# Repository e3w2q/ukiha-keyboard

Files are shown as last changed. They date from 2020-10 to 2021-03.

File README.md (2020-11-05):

# Ukiha




Small key pitch 5x12 ortholinear keyboard.

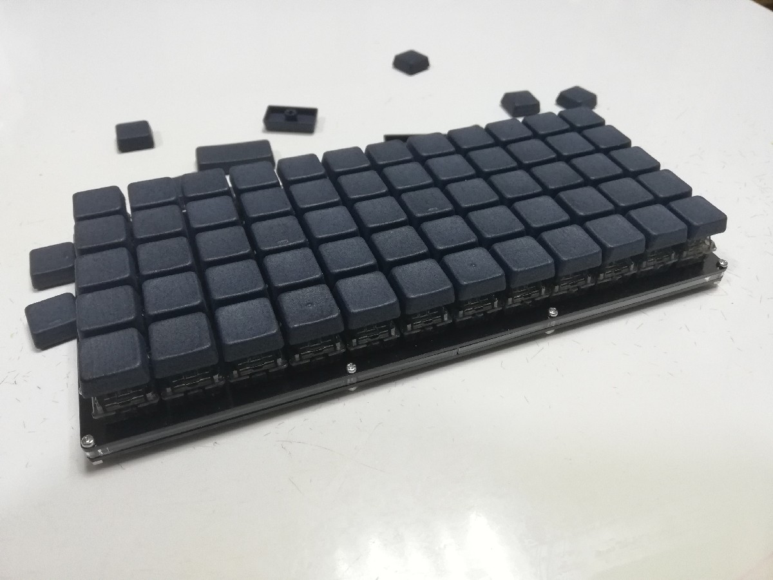
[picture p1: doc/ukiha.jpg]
ukiha


## What is the Ukiha?

The Ukiha is a 5x12 ortholinear keyboard like the Preonic and JJ50, but with a smaller key pitch of 16mm instead of 19.05mm.

I like expantable keyboard boards like [SU120](https://github.com/e3w2q/su120-keyboard) and [te96](https://github.com/e3w2q/te96-keyboard), but in this case I designed a keyboard that I genuinely wanted.

The *Ukiha* (浮葉) means "floating leaf" and is taken from the Japanese classic, *Pillow Book* (枕草子).

In the book, there is an example of a very small floating lotus leaf taken from a pond as a lovely thing.

うつくしきもの。(中略) 蓮の浮葉のいとちひさきを、池より取りあげたる。(枕草子 第百五十一段より)

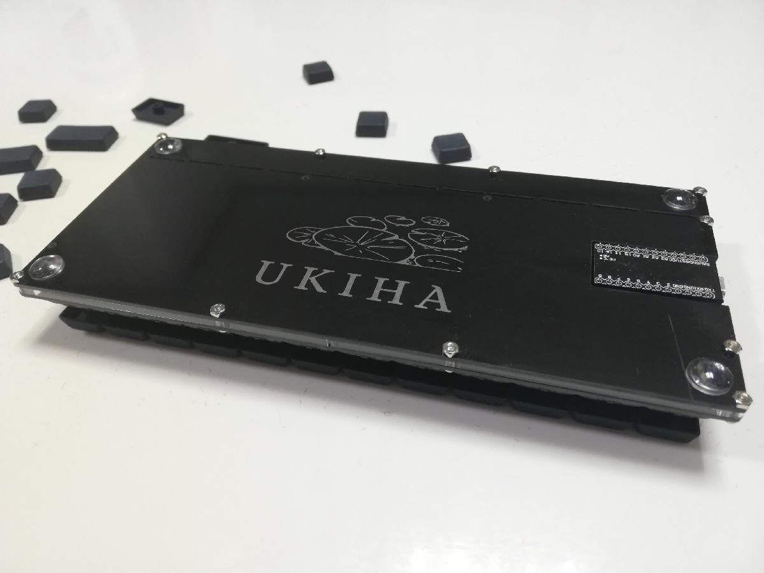
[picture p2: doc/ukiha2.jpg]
ukiha2


## Why open source?

Anyone interested in small key pitch keyboard could try.

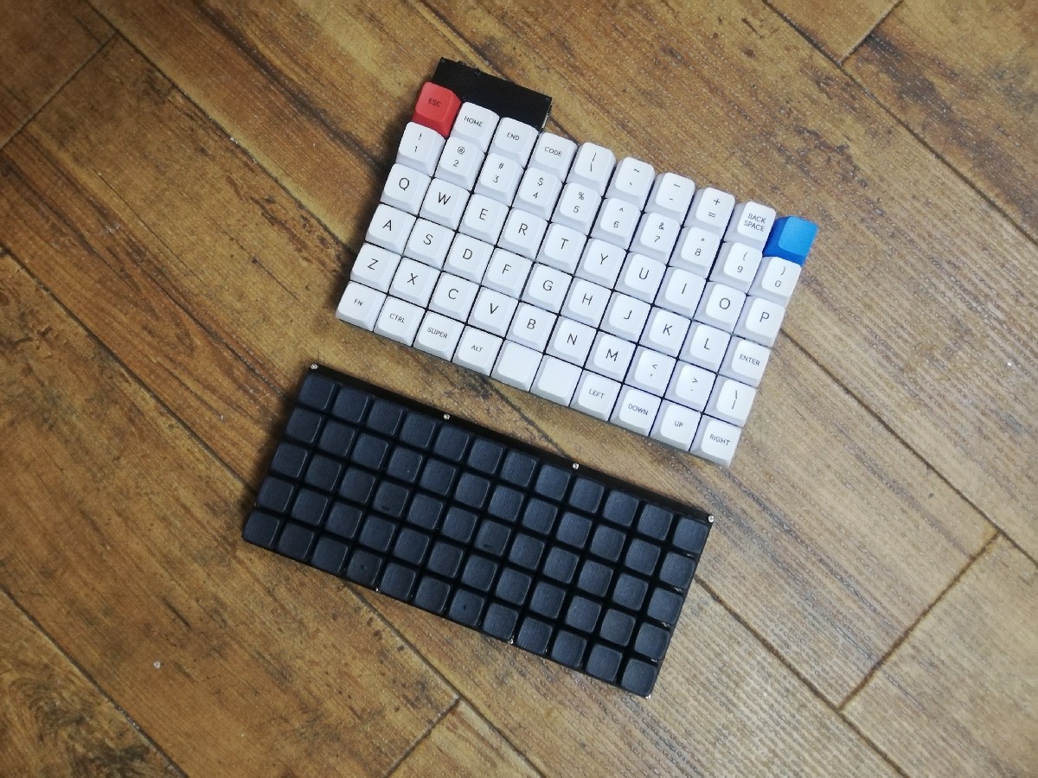
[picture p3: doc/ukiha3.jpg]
ukiha3


## Customizability

The 4 keys in the middle of the bottom row can be replaced with 2U.

You can take off the top row and make it into a 4x12 keyboard like Planck and JJ40.

## Link

[Hardware data (PCB)](pcb/)

[Firmware](https://github.com/e3w2q/qmk_firmware/tree/e3w2q/keyboards/e3w2q/ukiha)

[PCBの入手方法](doc/pcb_order_guide_jp.md)

[パーツリスト](doc/bom_list_jp.md)

[ビルドガイド](doc/readme_jp.md)

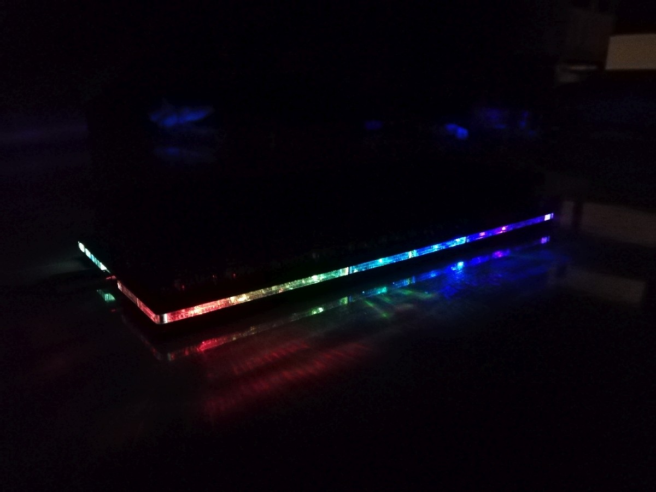
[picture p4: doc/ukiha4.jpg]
ukiha4


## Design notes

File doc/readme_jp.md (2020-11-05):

# 浮葉 ビルドガイド

<!-- TOC -->

- [浮葉 ビルドガイド](#浮葉-ビルドガイド)
    - [必要なパーツ](#必要なパーツ)
    - [使用する道具、消耗品](#使用する道具消耗品)
    - [ビルドガイド](#ビルドガイド)
        - [Pro Microのもげ防止加工](#pro-microのもげ防止加工)
        - [基板側面のヤスリがけ（お好みで）](#基板側面のヤスリがけお好みで)
        - [基板側面の塗装（お好みで）](#基板側面の塗装お好みで)
        - [はんだ付けのイメージトレーニング](#はんだ付けのイメージトレーニング)
        - [ダイオードの取り付け](#ダイオードの取り付け)
        - [キースイッチの取り付け](#キースイッチの取り付け)
        - [Pro Microの取り付け](#pro-microの取り付け)
        - [テープLEDの取り付け](#テープledの取り付け)
        - [ミドルプレート、ボトムプレートの取り付け](#ミドルプレートボトムプレートの取り付け)
        - [キーキャップの取り付け](#キーキャップの取り付け)
        - [ゴム足の取り付け](#ゴム足の取り付け)
        - [ファームウェアの書き込み](#ファームウェアの書き込み)
    - [トラブルシューティング](#トラブルシューティング)

<!-- /TOC -->

## 必要なパーツ

[浮葉 パーツリスト](bom_list_jp.md)をご覧ください。

## 使用する道具、消耗品

[使用する道具、消耗品](tool_guide_jp.md)におすすめの道具類、注意事項等をまとめましたのでご覧ください。

## ビルドガイド

### Pro Microのもげ防止加工

Pro Microにエポキシ接着剤を盛って、簡単にはもげないようにします。

参考1:[ProMicroのモゲ防止ついでにQMK_Firmwareを書き込む - Qiita](https://qiita.com/hdbx/items/2f3e4ddfcadda2a5578e)
参考2:[もげ予防 - Self-Made Keyboards in Japan](https://scrapbox.io/self-made-kbds-ja/%E3%82%82%E3%81%92%E4%BA%88%E9%98%B2)

エポキシ接着剤の2液を混ぜます。

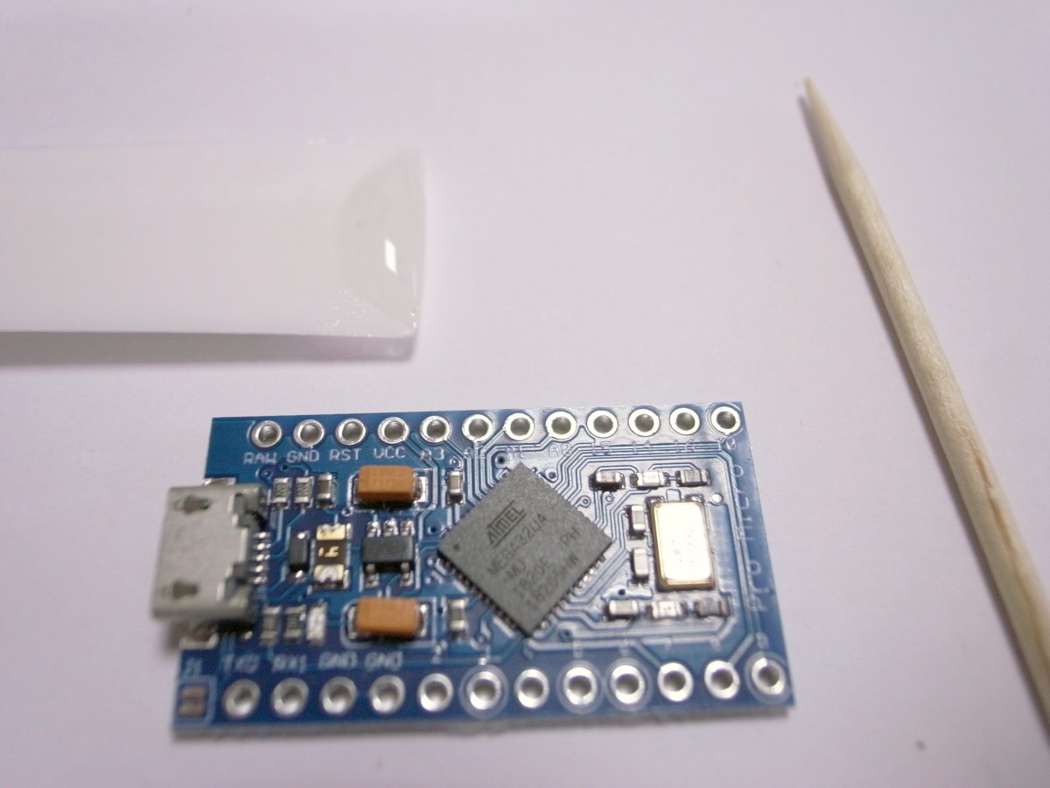
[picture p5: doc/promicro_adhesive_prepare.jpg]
adhesive_prepare


接着剤を付け始める前にMicro USBコネクタを横から見てください。側面に穴が開いています。この穴に接着剤が入ると端子が入らなくなったり、入りにくくなったりします。

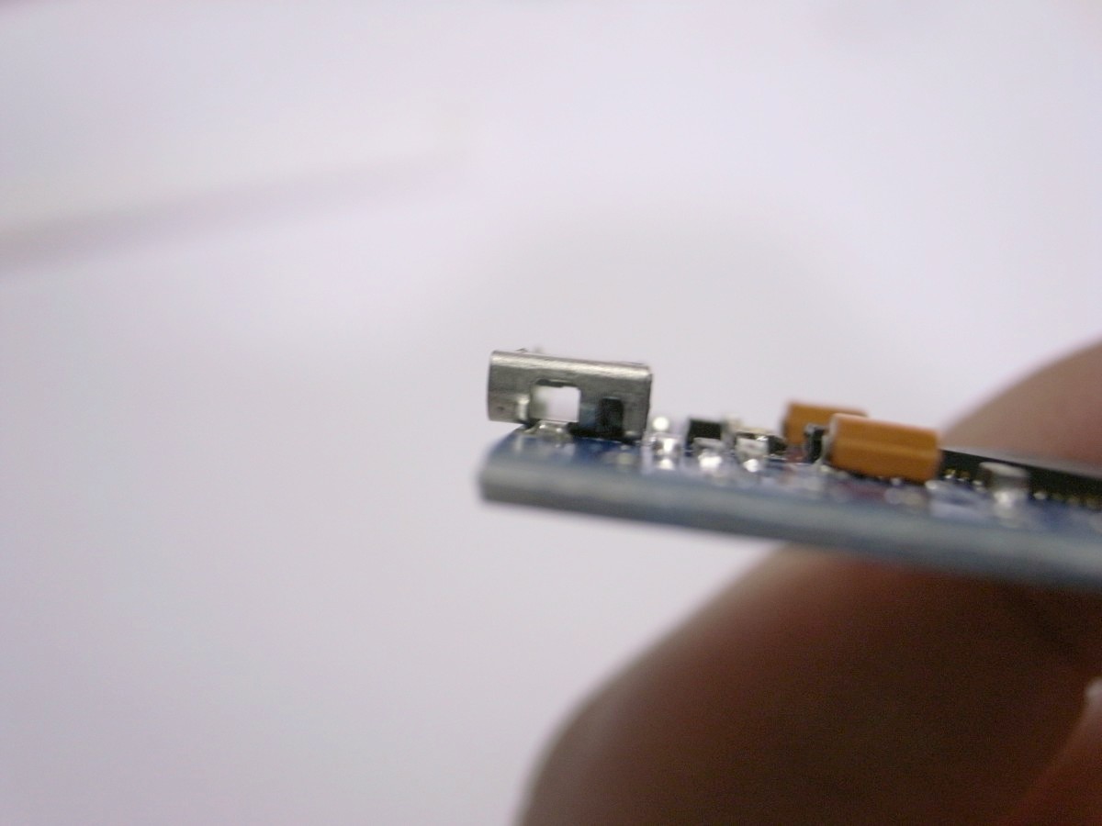
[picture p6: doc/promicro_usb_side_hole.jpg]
usb_side_hole


この穴を避けて、つまようじなどで接着剤を盛っていきます。

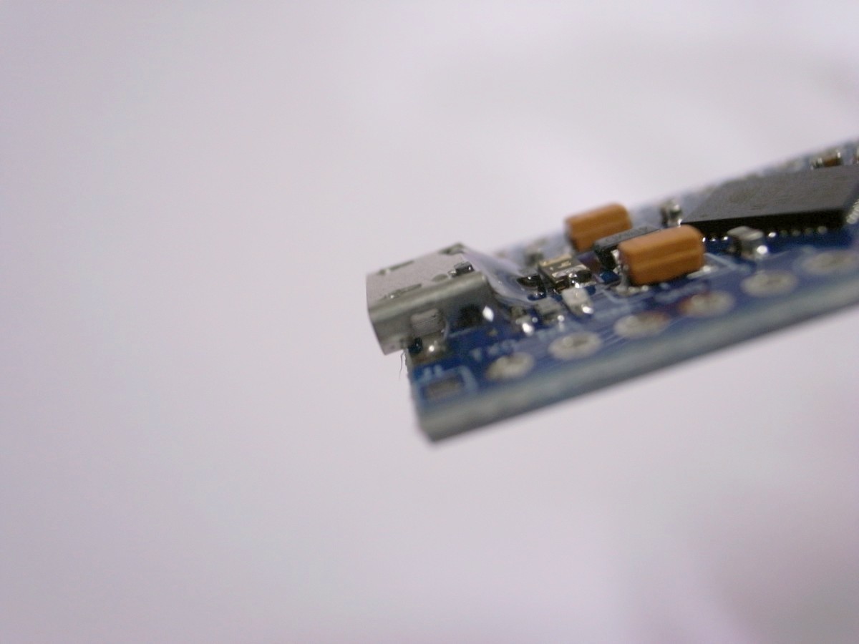
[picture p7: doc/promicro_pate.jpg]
promicro_pate


乾くまで置いておきます。

### 基板側面のヤスリがけ（お好みで）

基板の側面にザラつきがある場合、机に紙ヤスリを置き、その上で基板のバリがある側面をヤスリがけします。Pro Microの側面もヤスリがけします。

### 基板側面の塗装（お好みで）

基板の側面を太めのマジックで塗ります。細いマジックだとムラが出やすいので太めのマジックで一度に塗るとよいです。Twitterで@swan_matchさんにガンダムマーカーがよいと教えてもらいましたが、確かにきれいに塗れました。塗る場合はPro Microの側面も塗っておくとよいです。

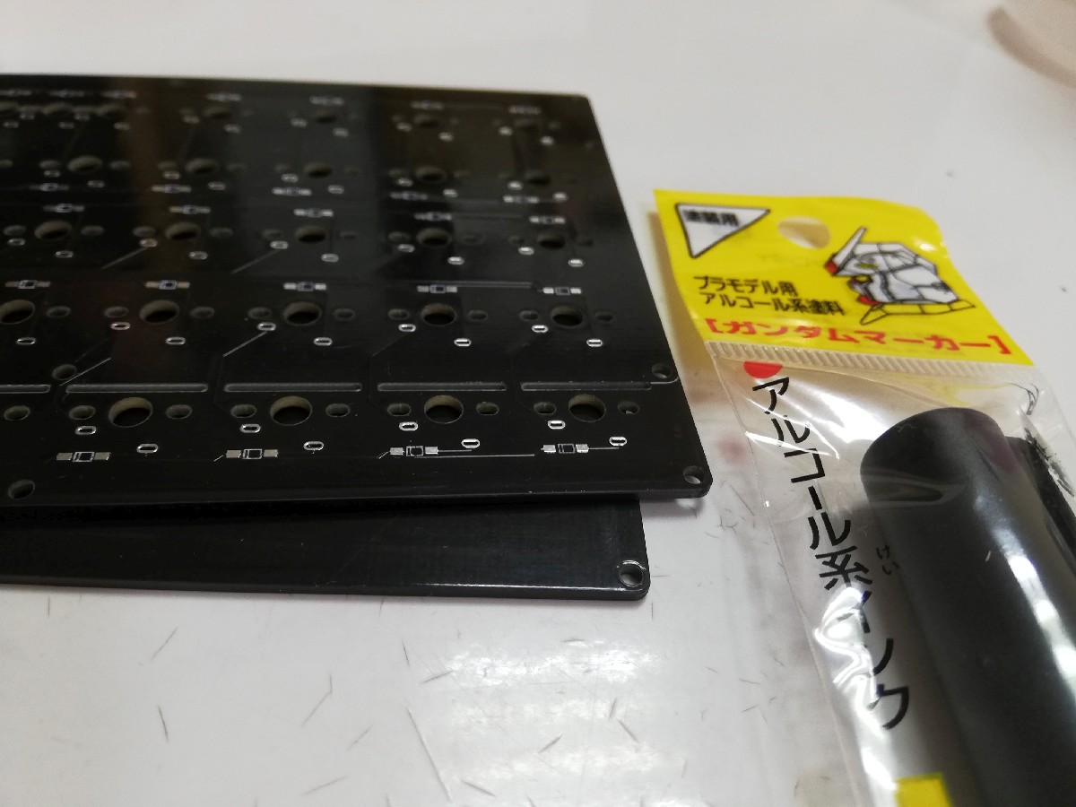
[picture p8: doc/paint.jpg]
paint


スリット部分はマッキー極細（0.5mm）でギリギリ塗れますが、塗るのがかなり大変ですし、側面のようによく目に付く場所ではないため、塗らなくてもよいと思います。

### はんだ付けのイメージトレーニング

はんだ付けに慣れている方は次の項に進んでください。

全くはんだ付けをしたことがなかったり、数年ぶりにはんだ付けをする場合は、以下の動画が参考になります。

- [はんだ付けの詳細.m2p - YouTube](https://www.youtube.com/watch?v=ZA-ehWjRfYM)

- [チップ抵抗のはんだ付けと、はんだ量の調整（体験用基板を使用） - YouTube](https://www.youtube.com/watch?v=vqKKElJ1vw0)

- [基礎からわかる！自キ入門講座 第8回「自作キーボードのつくりかた #2」 - YouTube](https://www.youtube.com/watch?v=LOC53FeU-QM&t=999)

### ダイオードの取り付け

**基板裏側**にキースイッチの数だけダイオードを取り付けます。

何も書いていない側が基板の表で、ダイオードの印が描いてあるほうが裏です。画像は裏側です。

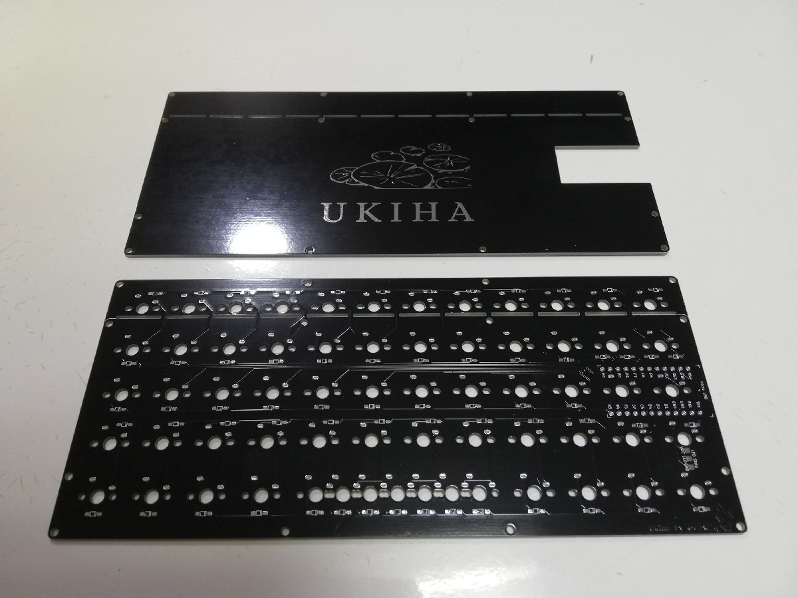
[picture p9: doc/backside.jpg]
backside


まず片方のパッド上にはんだを溶かして盛ります。以降の画像は時々別の基板だったりしますが、やることは同じです。

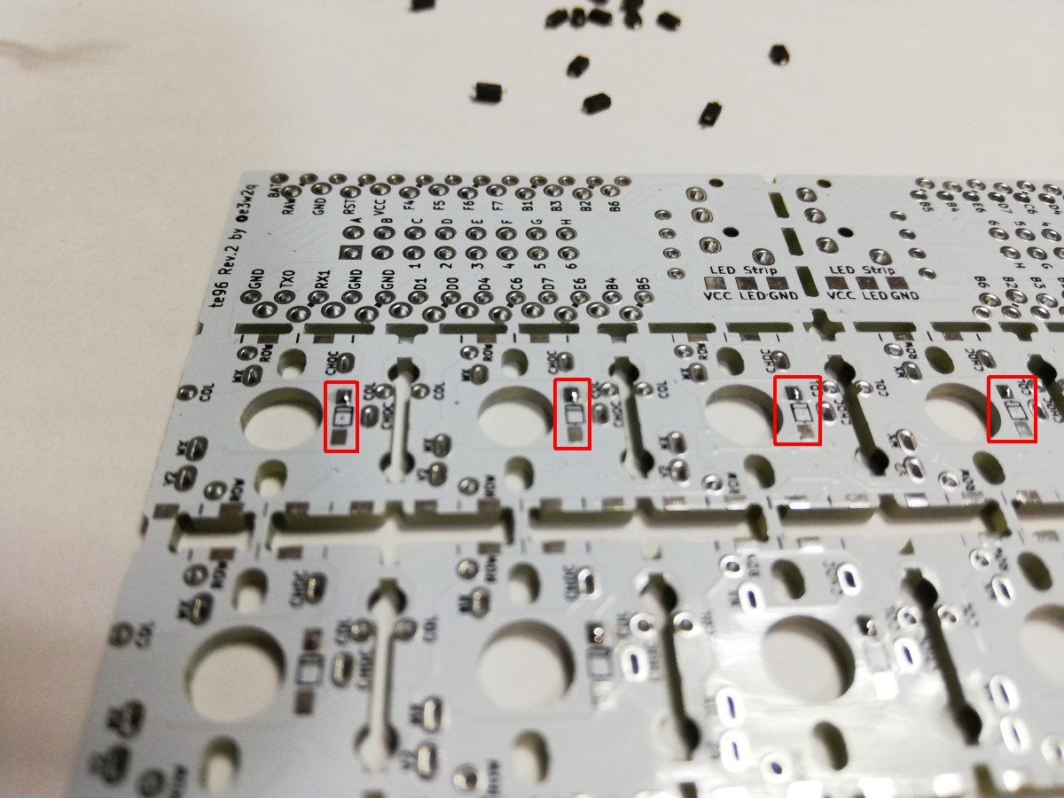
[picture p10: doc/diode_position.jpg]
diode_position


ダイオードをピンセットでつまみ、基板のシルク印刷の二重線と、表面実装ダイオードの二重線の向きを合わせて、パッドに置きます。

先程パッドに盛ったはんだを溶かしてダイオードの片側をはんだ付けします。

うまくいかない場合は以下の動画をご覧ください。

- [チップ抵抗のはんだ付けと、はんだ量の調整（体験用基板を使用） - YouTube](https://www.youtube.com/watch?v=vqKKElJ1vw0)

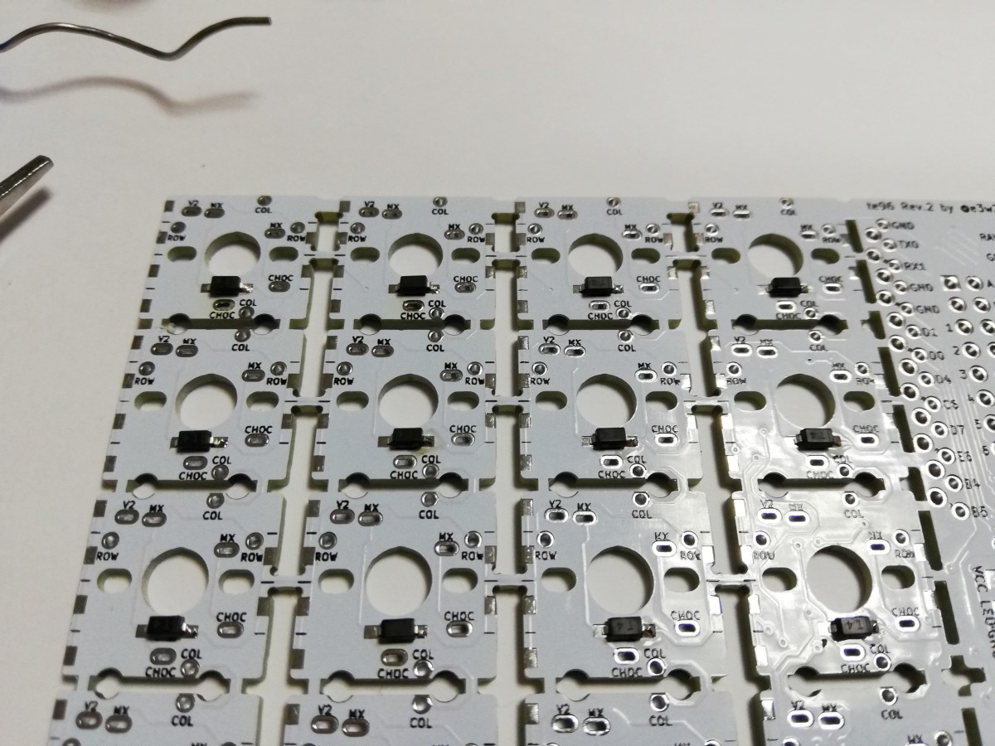
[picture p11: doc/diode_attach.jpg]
diode_attach


表面実装ダイオードのはんだ付けをしていない側をはんだ付けします。

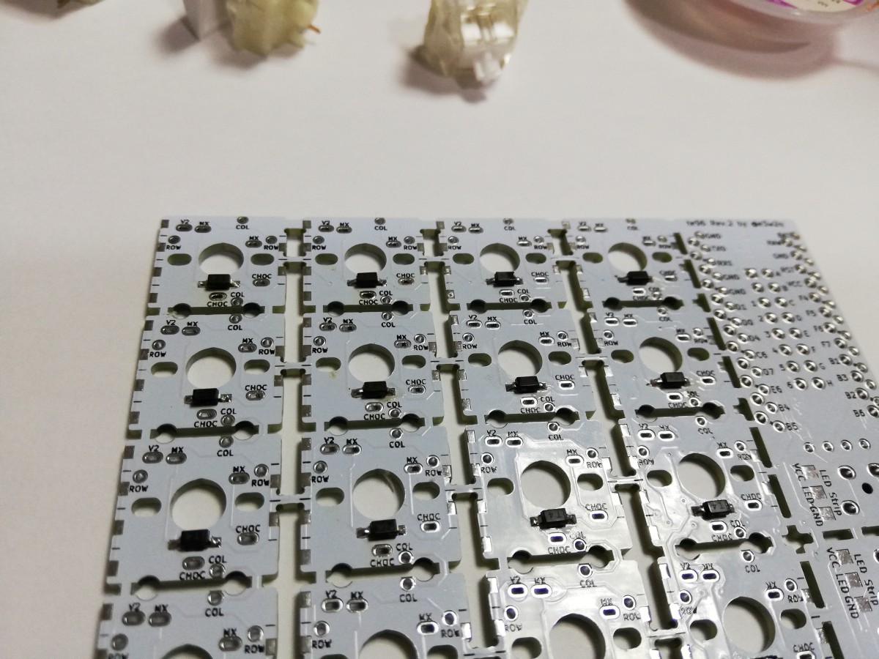
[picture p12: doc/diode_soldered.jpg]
diode_soldered


### キースイッチの取り付け

表側から差し込みます。トッププレート無しでもキースイッチのガタつきがないよう、穴のサイズを小さめにしてあります。キースイッチの足が曲がっている場合はまっすぐにしてから差し込んでください。

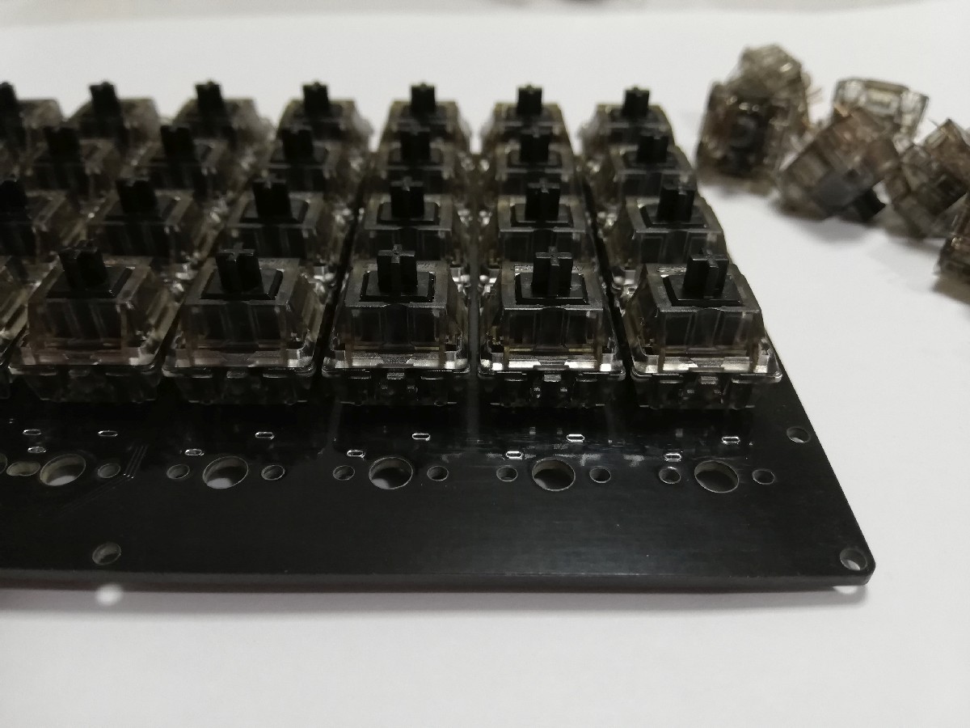
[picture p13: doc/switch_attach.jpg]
switch_attach


裏返します。

Pro Microが取り付けられる部分のスイッチ2個の足を基板からはみ出さないようにニッパーでカットしておきます。

ハンダ付けします。

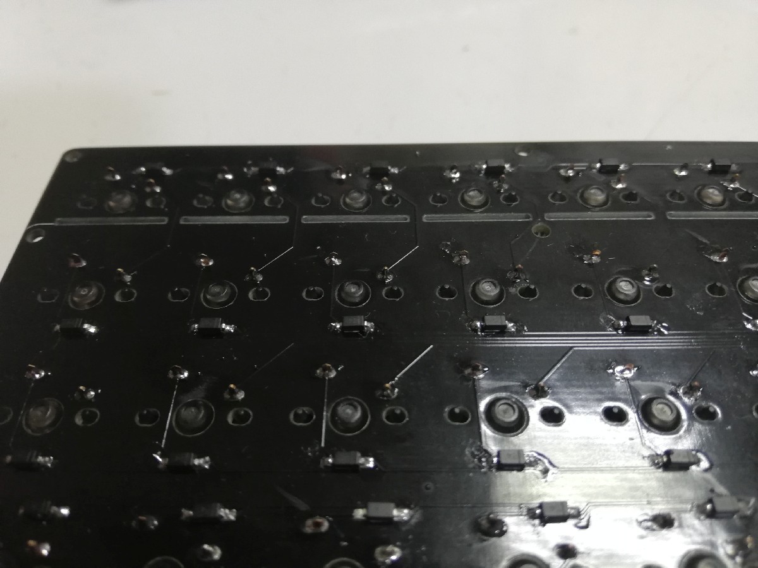
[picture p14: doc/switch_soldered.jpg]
switch_soldered


### Pro Microの取り付け

**基板裏側**のPro Micro設置部分のスルーホールに、コンスルーピンヘッダを根本まで差し込みます。

その際、

- コンスルーピンヘッダの金色の窓が遠い側を基板側とし、金色の窓が近い側をProMicro側とする
- 金色の窓の向きを揃える

ようにしてください。

参考: [Helixベータ ビルドガイド](https://github.com/MakotoKurauchi/helix/blob/master/Doc/buildguide_jp.md#pro-micro)

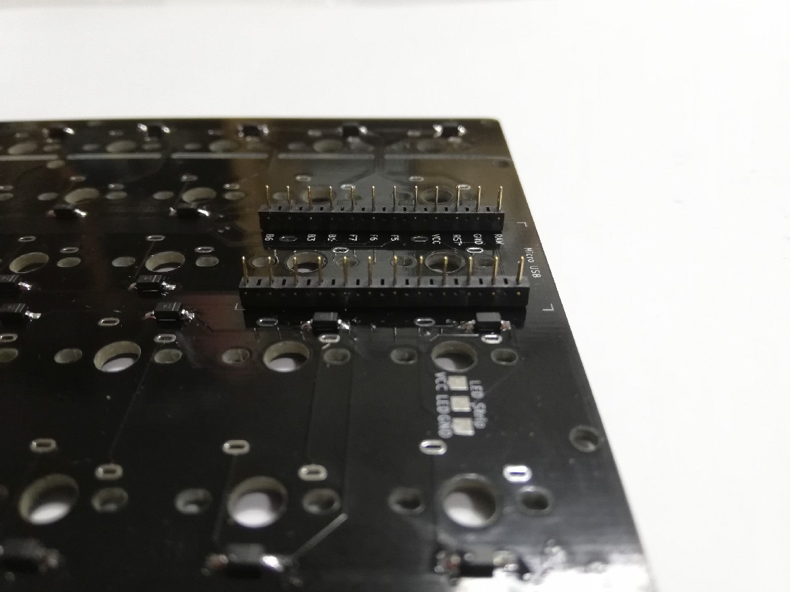
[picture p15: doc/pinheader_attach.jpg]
pinheader_attach


ピンヘッダにPro Microを差し込みます。**Pro Microの裏面（平らなほう）が上になるように、またマイクロUSBが基板端になるように**します。

**向きを間違えるとリカバリーが大変です。表裏、左右をよく確認してください。**

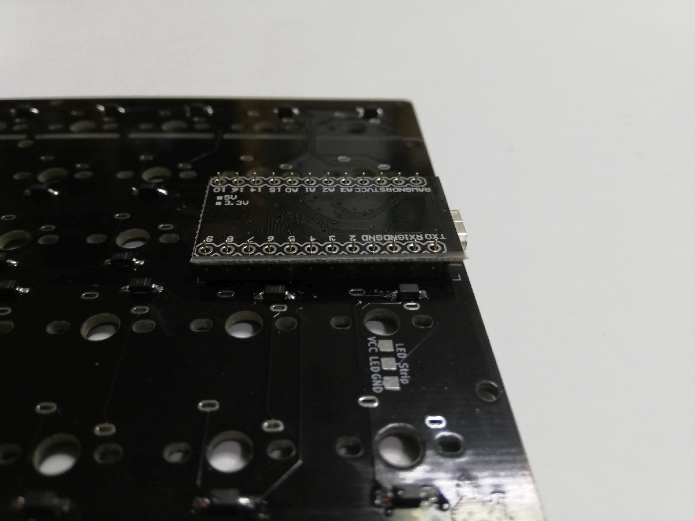
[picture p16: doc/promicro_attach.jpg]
promicro_attach


Pro Microとコンスルーピンヘッダをハンダ付けします。まず四隅をハンダ付けし、横から見てコンスルーピンヘッダとの間に隙間があれば押さえながらハンダを温めて浮かないようにします。そのあと、順番に全てハンダ付けします。

基板とコンスルーピンヘッダは接触しているため、ハンダ付けしません。

### テープLEDの取り付け

基板裏のPro Microの近くの`LED Stripe`と印字してある場所のパッドにテープLEDをハンダ付けします。

ハンダ付けの前にテープLEDの向き、端子の並びを確認してください。また、スイッチの端子と重ならないようにマスキングテープで仮止めしてください。

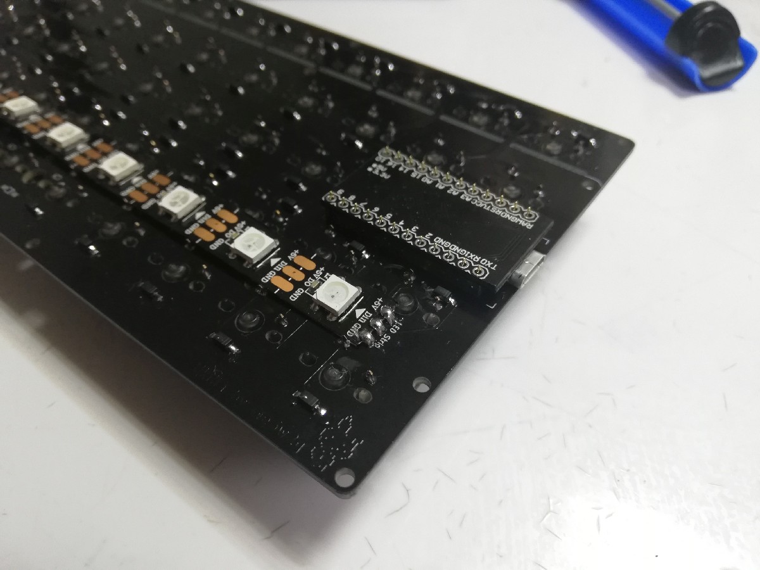
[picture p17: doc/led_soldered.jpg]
led_soldered


### ミドルプレート、ボトムプレートの取り付け

基板の上に、テープLEDとPro Microに干渉しないようにミドルプレートを置きます。

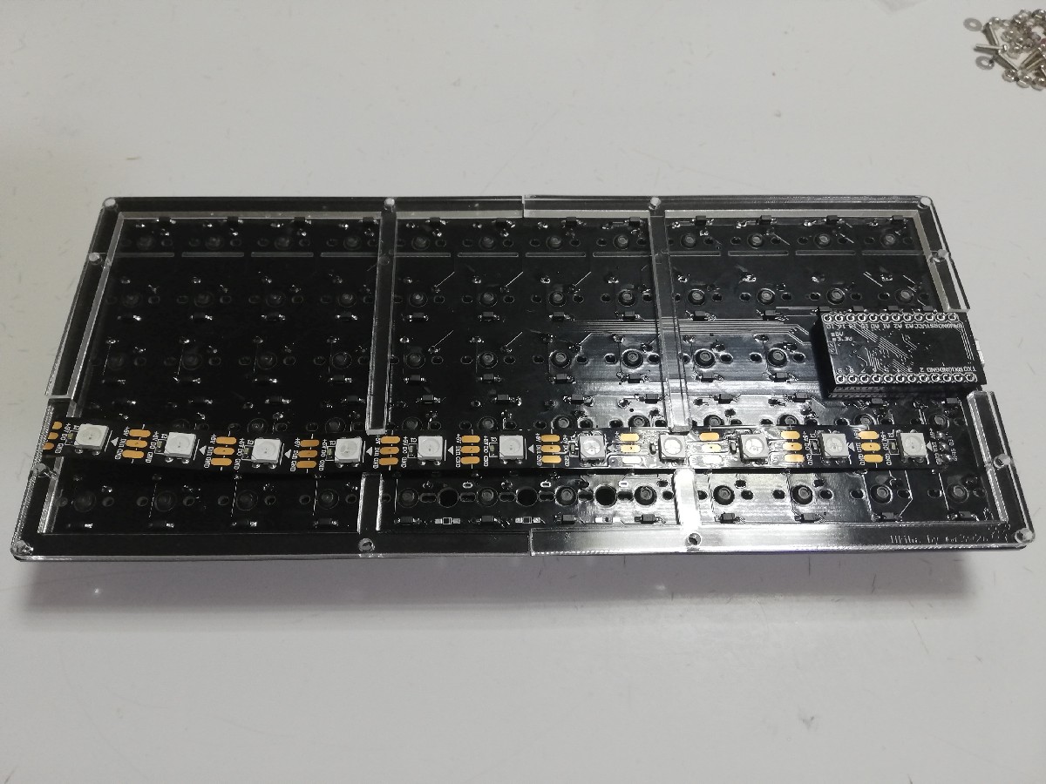
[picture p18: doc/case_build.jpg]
case_build


さらにボトムプレートを置きます。基板の表側からネジ穴にM2ネジを差し込み、ナットを締めます。

### キーキャップの取り付け

キースイッチにキーキャップ（16mmキーピッチに適合するもの）をはめます。

### ゴム足の取り付け

ゴム足を裏面の四隅に取り付けます。

### ファームウェアの書き込み

以下のリンク先を参考にして、QMK Firmwareのビルド環境を用意します。

- Windows
  - [QMKビルド環境の構築(Windows Msys2編)](https://gist.github.com/e3w2q/4bc86e531d1c893d3d13af3e9895a94a)
- macOS
  - [セットアップ - QMK Firmware](https://docs.qmk.fm/#/ja/newbs_getting_started?id=macos)
- Linux
  - [セットアップ - QMK Firmware](https://docs.qmk.fm/#/ja/newbs_getting_started?id=linux)

構築中、

```
qmk setup
```

と入力する代わりに

```
qmk setup e3w2q/qmk_firmware --branch e3w2q
```

と入力してください。

または、`qmk setup`した後に、`C:\Users\USER_NAME\qmk_firmware\keyboards`配下に[https://github.com/e3w2q/qmk_firmware/tree/e3w2q/keyboards/e3w2q](https://github.com/e3w2q/qmk_firmware/tree/e3w2q/keyboards/e3w2q)以下をコピーしてもよいです。

用意されたキーマップを書き込むには以下を実行します。

```
qmk flash -kb e3w2q/ukiha -km default
```

`Detecting USB port, reset your controller now...`と表示されたらPro Microの`GND`と`RST`をピンセットやクリップなどで短絡させると書き込みが始まります。

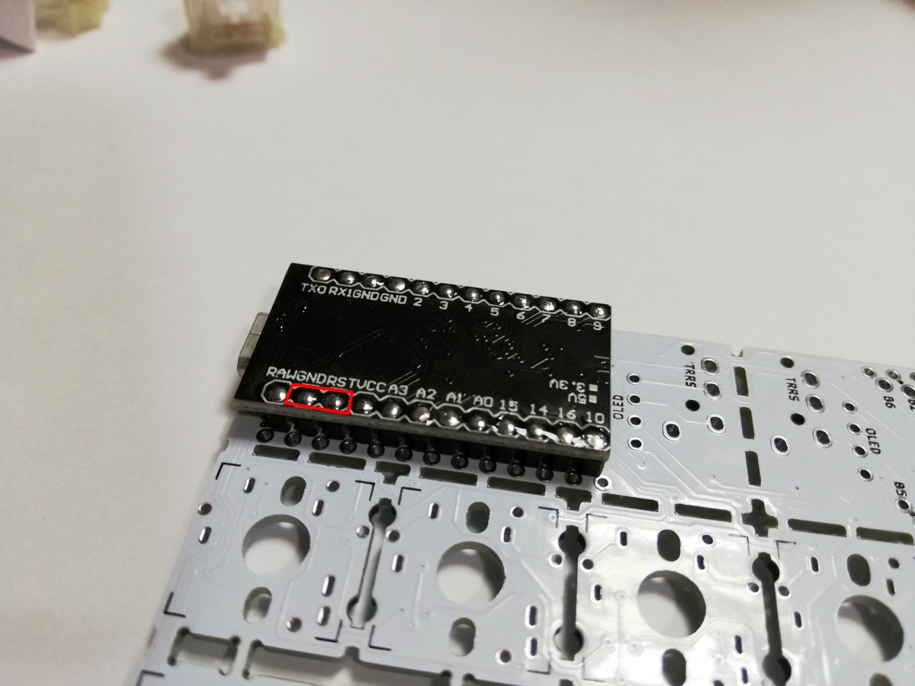
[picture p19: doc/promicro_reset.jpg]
promicro_reset


[QMK Configuratorのテストモード](https://config.qmk.fm/#/test)でキー入力が行えるかテストしてください。

## トラブルシューティング

- 特定のキーが反応しない
  - キースイッチのハンダ付けが甘い場合があります。キースイッチを押すかわりに、キースイッチの裏面のハンダ2箇所をピンセットでショートさせてみて、入力されるか確認してください。入力される場合は、ハンダ付けし直してみてください。
- 行、列単位でキーが反応しない
  - Pro Microと基板がうまく導通していない可能性があります。該当する行または列のPro Microの足をハンダ付けし直してみてください。

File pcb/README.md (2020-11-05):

# Ukiha PCB Data

## Schematic
[Schematic PDF](../doc/schematic.pdf?raw=true)
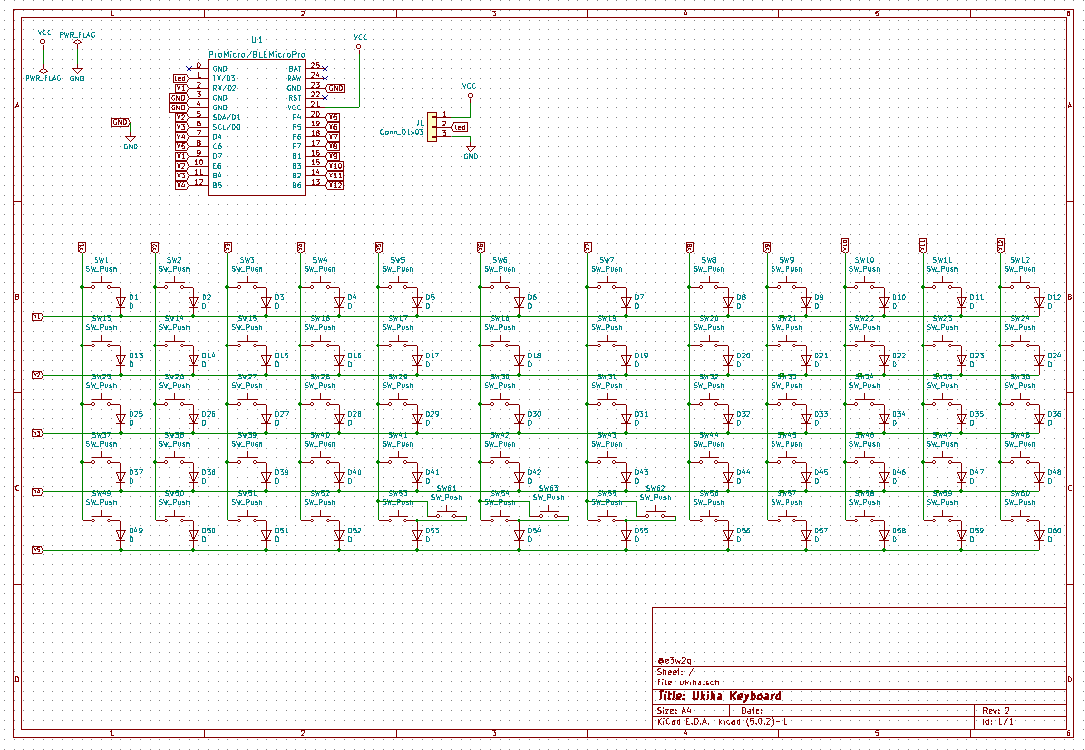
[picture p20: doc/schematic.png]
Schematic


## PCB Layout
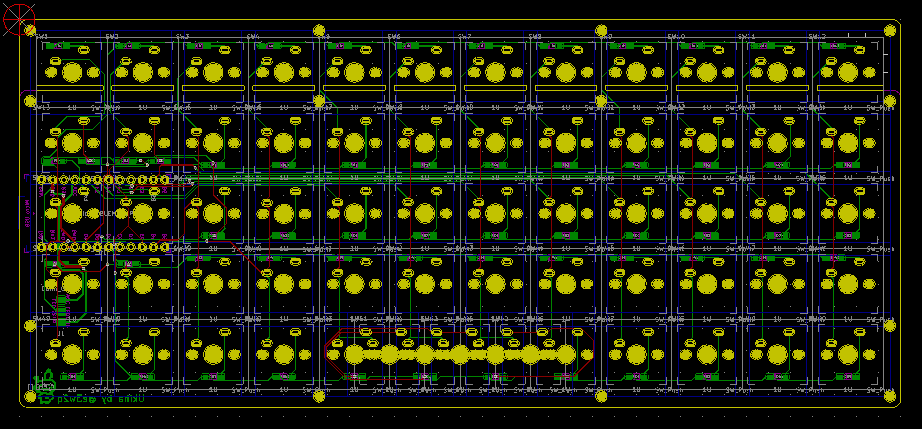
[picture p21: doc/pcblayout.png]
PCB Layout

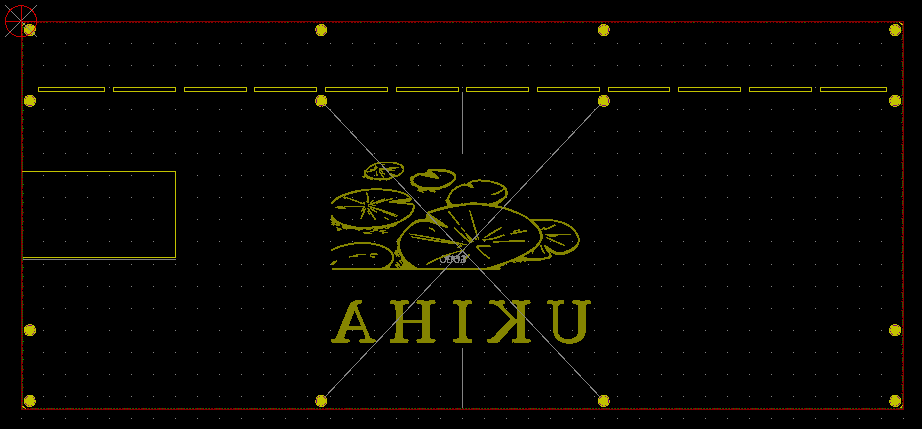
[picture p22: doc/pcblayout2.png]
PCB Layout


## Acrylic Layout
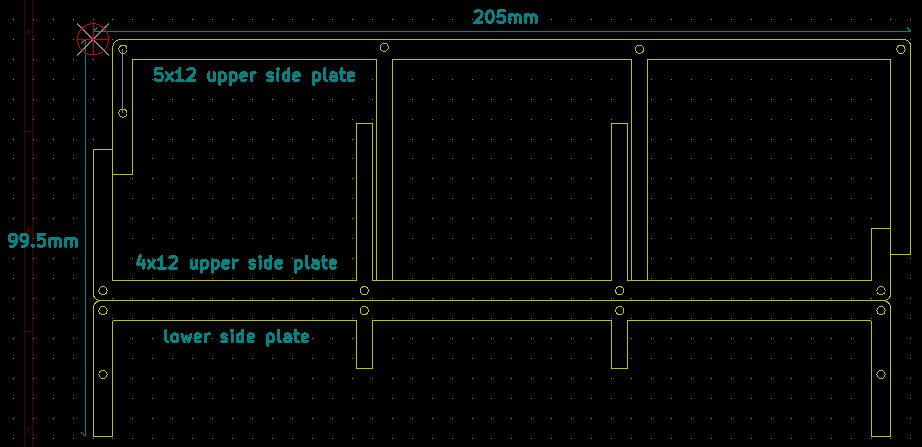
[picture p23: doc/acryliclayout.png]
Acrylic Layout


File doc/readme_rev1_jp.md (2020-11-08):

# 浮葉 Rev.1 ビルドガイド

**最新版はRev.2です。Rev.1には以下の不備があります。**

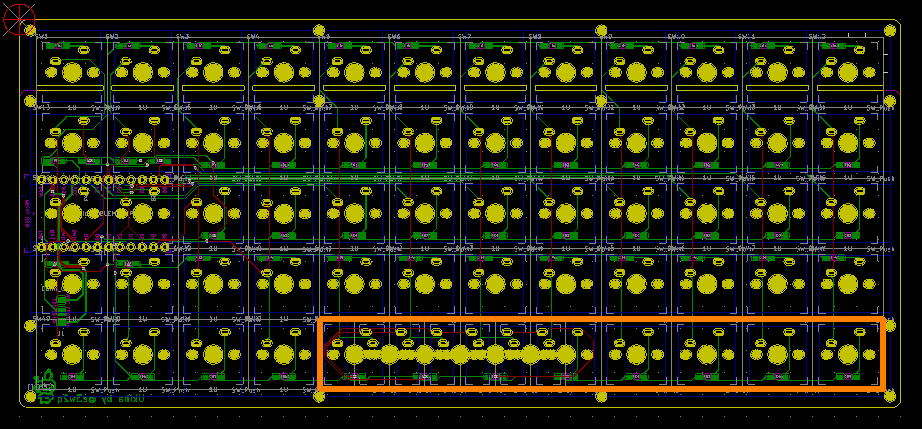
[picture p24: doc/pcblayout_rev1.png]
pcblayout_rev1
- **最下段の右から8キー分の固定穴にミスがあり、MX互換スイッチを使う場合は3ピンのものを使うか、固定ピンをカットする必要があります。**
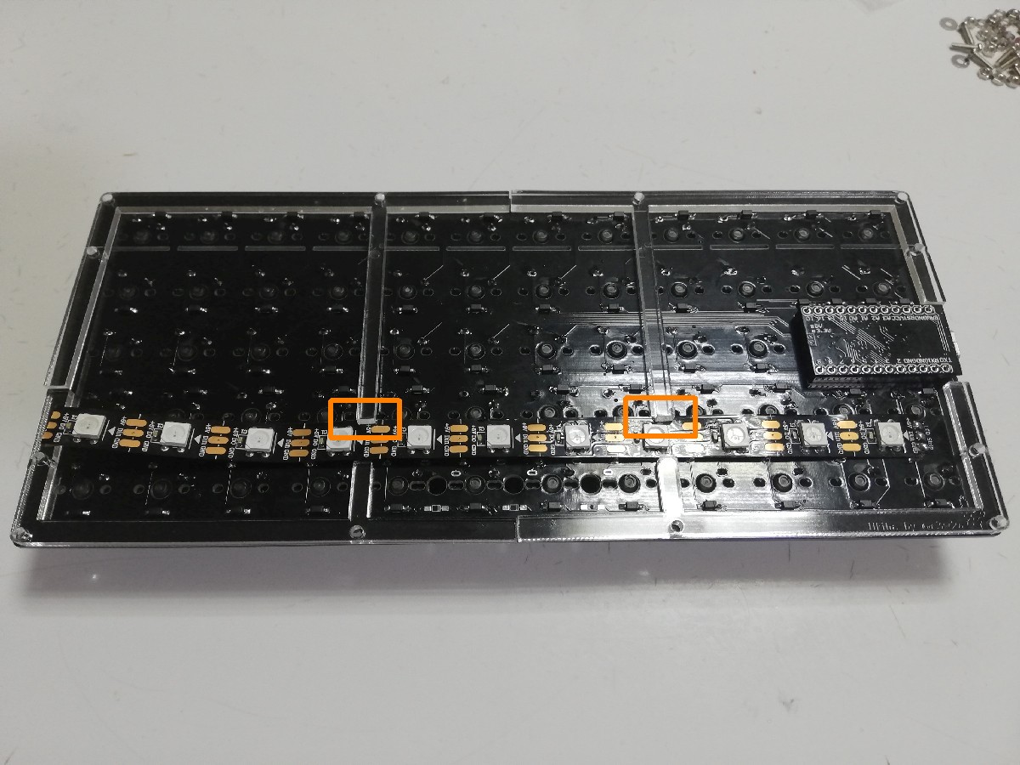
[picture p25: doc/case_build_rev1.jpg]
case_build_rev1
- **ミドルプレートの内壁が少し長く、テープLEDに少し被せる必要があります。**
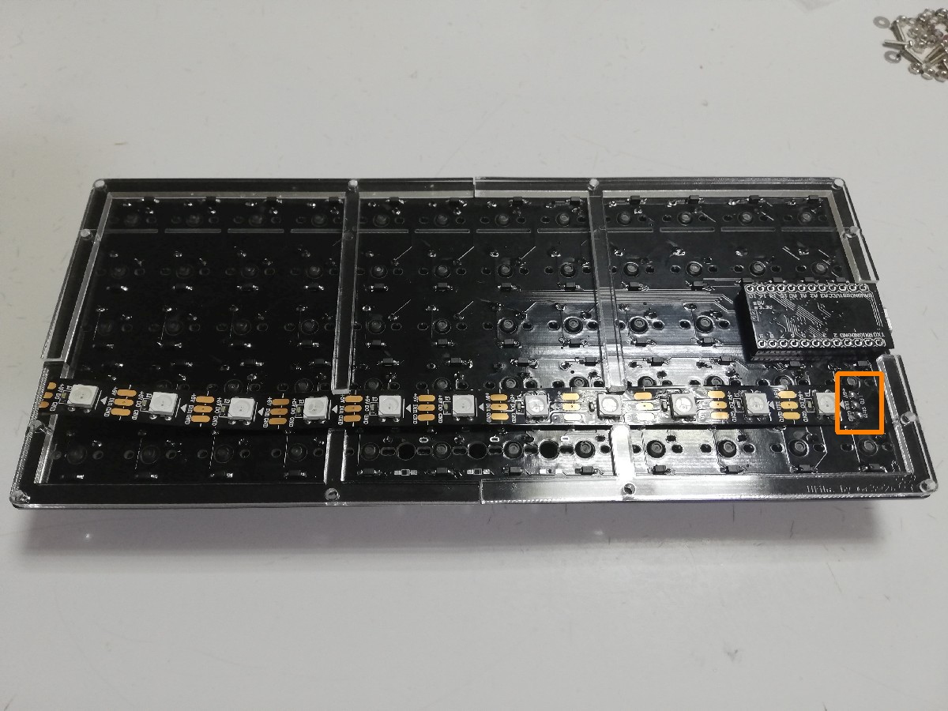
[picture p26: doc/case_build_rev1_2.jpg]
case_build_rev1_2
- **テープLEDのハンダ付け位置が少し内側に寄っています。**
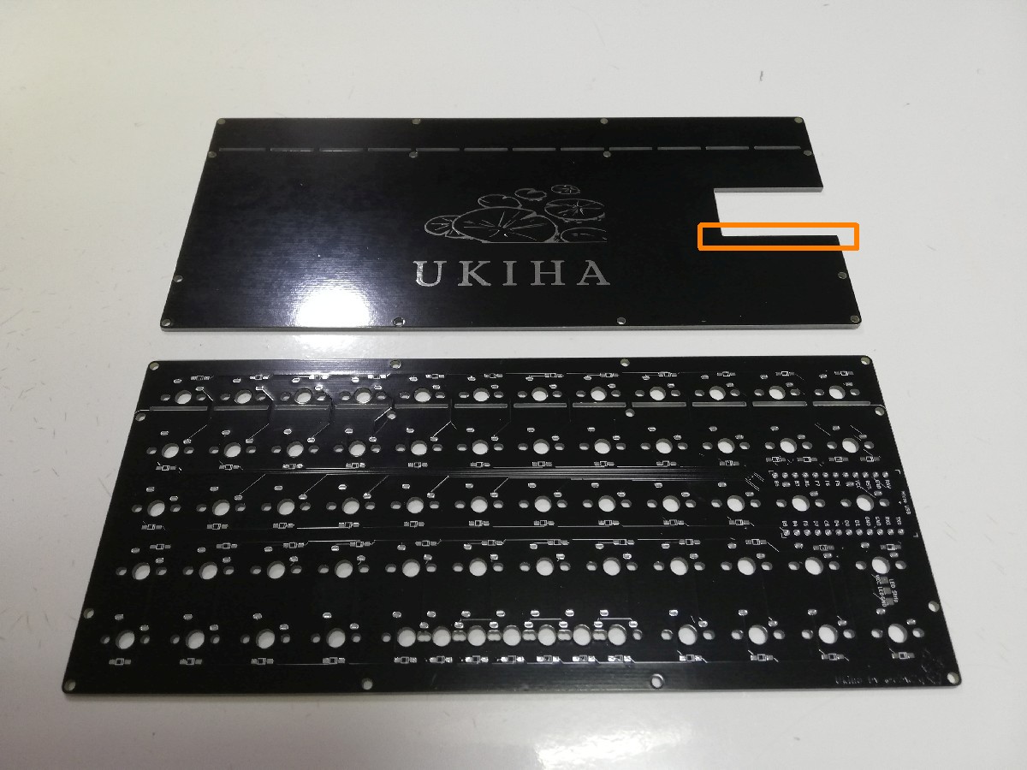
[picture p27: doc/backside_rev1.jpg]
backside_rev1
- **ボトムプレートのPro Microの隙間の片側が少し広くなっています。**

<!-- TOC -->

- [浮葉 ビルドガイド](#浮葉-ビルドガイド)
    - [必要なパーツ](#必要なパーツ)
    - [使用する道具、消耗品](#使用する道具消耗品)
    - [ビルドガイド](#ビルドガイド)
        - [Pro Microのもげ防止加工](#pro-microのもげ防止加工)
        - [基板側面のヤスリがけ（お好みで）](#基板側面のヤスリがけお好みで)
        - [基板側面の塗装（お好みで）](#基板側面の塗装お好みで)
        - [はんだ付けのイメージトレーニング](#はんだ付けのイメージトレーニング)
        - [ダイオードの取り付け](#ダイオードの取り付け)
        - [キースイッチの取り付け](#キースイッチの取り付け)
        - [Pro Microの取り付け](#pro-microの取り付け)
        - [テープLEDの取り付け](#テープledの取り付け)
        - [ミドルプレート、ボトムプレートの取り付け](#ミドルプレートボトムプレートの取り付け)
        - [キーキャップの取り付け](#キーキャップの取り付け)
        - [ゴム足の取り付け](#ゴム足の取り付け)
        - [ファームウェアの書き込み](#ファームウェアの書き込み)
    - [トラブルシューティング](#トラブルシューティング)

<!-- /TOC -->

## 必要なパーツ

[浮葉 パーツリスト](bom_list_jp.md)をご覧ください。

## 使用する道具、消耗品

[使用する道具、消耗品](tool_guide_jp.md)におすすめの道具類、注意事項等をまとめましたのでご覧ください。

## ビルドガイド

### Pro Microのもげ防止加工

Pro Microにエポキシ接着剤を盛って、簡単にはもげないようにします。

参考1:[ProMicroのモゲ防止ついでにQMK_Firmwareを書き込む - Qiita](https://qiita.com/hdbx/items/2f3e4ddfcadda2a5578e)
参考2:[もげ予防 - Self-Made Keyboards in Japan](https://scrapbox.io/self-made-kbds-ja/%E3%82%82%E3%81%92%E4%BA%88%E9%98%B2)

エポキシ接着剤の2液を混ぜます。

adhesive_prepare

接着剤を付け始める前にMicro USBコネクタを横から見てください。側面に穴が開いています。この穴に接着剤が入ると端子が入らなくなったり、入りにくくなったりします。

usb_side_hole

この穴を避けて、つまようじなどで接着剤を盛っていきます。

promicro_pate

乾くまで置いておきます。

### 基板側面のヤスリがけ（お好みで）

基板の側面にザラつきがある場合、机に紙ヤスリを置き、その上で基板のバリがある側面をヤスリがけします。Pro Microの側面もヤスリがけします。

### 基板側面の塗装（お好みで）

基板の側面を太めのマジックで塗ります。細いマジックだとムラが出やすいので太めのマジックで一度に塗るとよいです。Twitterで@swan_matchさんにガンダムマーカーがよいと教えてもらいましたが、確かにきれいに塗れました。塗る場合はPro Microの側面も塗っておくとよいです。

paint

スリット部分はマッキー極細（0.5mm）でギリギリ塗れますが、塗るのがかなり大変ですし、側面のようによく目に付く場所ではないため、塗らなくてもよいと思います。

### はんだ付けのイメージトレーニング

はんだ付けに慣れている方は次の項に進んでください。

全くはんだ付けをしたことがなかったり、数年ぶりにはんだ付けをする場合は、以下の動画が参考になります。

- [はんだ付けの詳細.m2p - YouTube](https://www.youtube.com/watch?v=ZA-ehWjRfYM)

- [チップ抵抗のはんだ付けと、はんだ量の調整（体験用基板を使用） - YouTube](https://www.youtube.com/watch?v=vqKKElJ1vw0)

- [基礎からわかる！自キ入門講座 第8回「自作キーボードのつくりかた #2」 - YouTube](https://www.youtube.com/watch?v=LOC53FeU-QM&t=999)

### ダイオードの取り付け

**基板裏側**にキースイッチの数だけダイオードを取り付けます。

何も書いていない側が基板の表で、ダイオードの印が描いてあるほうが裏です。画像は裏側です。

backside

まず片方のパッド上にはんだを溶かして盛ります。以降の画像は時々別の基板だったりしますが、やることは同じです。

diode_position

ダイオードをピンセットでつまみ、基板のシルク印刷の二重線と、表面実装ダイオードの二重線の向きを合わせて、パッドに置きます。

先程パッドに盛ったはんだを溶かしてダイオードの片側をはんだ付けします。

うまくいかない場合は以下の動画をご覧ください。

- [チップ抵抗のはんだ付けと、はんだ量の調整（体験用基板を使用） - YouTube](https://www.youtube.com/watch?v=vqKKElJ1vw0)

diode_attach

表面実装ダイオードのはんだ付けをしていない側をはんだ付けします。

diode_soldered

### キースイッチの取り付け

表側から差し込みます。トッププレート無しでもキースイッチのガタつきがないよう、穴のサイズを小さめにしてあります。キースイッチの足が曲がっている場合はまっすぐにしてから差し込んでください。

switch_attach

裏返します。

Pro Microが取り付けられる部分のスイッチ2個の足を基板からはみ出さないようにニッパーでカットしておきます。

ハンダ付けします。

switch_soldered

### Pro Microの取り付け

**基板裏側**のPro Micro設置部分のスルーホールに、コンスルーピンヘッダを根本まで差し込みます。

その際、

- コンスルーピンヘッダの金色の窓が遠い側を基板側とし、金色の窓が近い側をProMicro側とする
- 金色の窓の向きを揃える

ようにしてください。

参考: [Helixベータ ビルドガイド](https://github.com/MakotoKurauchi/helix/blob/master/Doc/buildguide_jp.md#pro-micro)

pinheader_attach

ピンヘッダにPro Microを差し込みます。**Pro Microの裏面（平らなほう）が上になるように、またマイクロUSBが基板端になるように**します。

**向きを間違えるとリカバリーが大変です。表裏、左右をよく確認してください。**

promicro_attach

Pro Microとコンスルーピンヘッダをハンダ付けします。まず四隅をハンダ付けし、横から見てコンスルーピンヘッダとの間に隙間があれば押さえながらハンダを温めて浮かないようにします。そのあと、順番に全てハンダ付けします。

基板とコンスルーピンヘッダは接触しているため、ハンダ付けしません。

### テープLEDの取り付け

基板裏のPro Microの近くの`LED Stripe`と印字してある場所のパッドにテープLEDをハンダ付けします。

ハンダ付けの前にテープLEDの向き、端子の並びを確認してください。また、スイッチの端子と重ならないようにマスキングテープで仮止めしてください。

led_soldered

### ミドルプレート、ボトムプレートの取り付け

基板の上に、テープLEDとPro Microに干渉しないようにミドルプレートを置きます。

case_build

さらにボトムプレートを置きます。基板の表側からネジ穴にM2ネジを差し込み、ナットを締めます。

### キーキャップの取り付け

キースイッチにキーキャップ（16mmキーピッチに適合するもの）をはめます。

### ゴム足の取り付け

ゴム足を裏面の四隅に取り付けます。

### ファームウェアの書き込み

以下のリンク先を参考にして、QMK Firmwareのビルド環境を用意します。

- Windows
  - [QMKビルド環境の構築(Windows Msys2編)](https://gist.github.com/e3w2q/4bc86e531d1c893d3d13af3e9895a94a)
- macOS
  - [セットアップ - QMK Firmware](https://docs.qmk.fm/#/ja/newbs_getting_started?id=macos)
- Linux
  - [セットアップ - QMK Firmware](https://docs.qmk.fm/#/ja/newbs_getting_started?id=linux)

構築中、

```
qmk setup
```

と入力する代わりに

```
qmk setup e3w2q/qmk_firmware --branch e3w2q
```

と入力してください。

または、`qmk setup`した後に、`C:\Users\USER_NAME\qmk_firmware\keyboards`配下に[https://github.com/e3w2q/qmk_firmware/tree/e3w2q/keyboards/e3w2q](https://github.com/e3w2q/qmk_firmware/tree/e3w2q/keyboards/e3w2q)以下をコピーしてもよいです。

用意されたキーマップを書き込むには以下を実行します。

```
qmk flash -kb e3w2q/ukiha -km default
```

`Detecting USB port, reset your controller now...`と表示されたらPro Microの`GND`と`RST`をピンセットやクリップなどで短絡させると書き込みが始まります。

promicro_reset

[QMK Configuratorのテストモード](https://config.qmk.fm/#/test)でキー入力が行えるかテストしてください。

## トラブルシューティング

- 特定のキーが反応しない
  - キースイッチのハンダ付けが甘い場合があります。キースイッチを押すかわりに、キースイッチの裏面のハンダ2箇所をピンセットでショートさせてみて、入力されるか確認してください。入力される場合は、ハンダ付けし直してみてください。
- 行、列単位でキーが反応しない
  - Pro Microと基板がうまく導通していない可能性があります。該当する行または列のPro Microの足をハンダ付けし直してみてください。

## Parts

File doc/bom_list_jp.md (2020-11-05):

# 浮葉 パーツリスト

| 名前 | 数 | 備考 | 調達先の例 | 参考価格 |
| --- | --- | --- | --- | --- |
| 浮葉 基板 | 1枚 | [入手方法はこちら](pcb_order_guide_jp.md) | [Elecrow Online store](https://www.elecrow.com/) | 5枚で$25.44 |
| 浮葉 ミドルプレート | 1セット | [入手方法はこちら](pcb_order_guide_jp.md) | [Elecrow Online store](https://www.elecrow.com/) | 分割型の場合5枚で$9.05 |
| 浮葉 ボトムプレート | 1枚 | [入手方法はこちら](pcb_order_guide_jp.md) | [Elecrow Online store](https://www.elecrow.com/) | 5枚で$25.44 |
| Pro Micro | 1個 | | https://talpkeyboard.stores.jp/items/5b24504ba6e6ee7ec60063e3 | 550円 |
| コンスルーピンヘッダ | 2個 | | https://talpkeyboard.stores.jp/items/5e056626d790db16e2889233 | 220円 |
| ダイオード 1N4148W | 60個（4×12で使うなら48個） | 表面実装タイプを使用 | https://yushakobo.jp/shop/a0800di-02-100/ | 100個で220円 |
| テープLED | 18cm程度の長さ |  | https://akizukidenshi.com/catalog/g/gM-12982/ | 1mで1,350円 |
| 5ピン仕様のMX互換スイッチ または Kailh Mid-Heightスイッチ | 60個（4×12で使うなら48個） | | https://talpkeyboard.stores.jp/?category_id=59cf8860ed05e668db003f5d | 10個で450円～  |
| 16mmキーピッチで利用可能なキーキャップ | 60個（4×12で使うなら48個） | [こちらの記事](https://e3w2q.github.io/10/)の16mmキーピッチ以下のもの | https://talpkeyboard.stores.jp/items/5f5444c380933970d139e98c | 2個で150円など |
| クッションゴム | 4個 | | ダイソー クッションゴム 14個入り または すべりどめシート | 110円 |
| 8mm長M2ネジ | 12本（4×12で使うなら10本） | |  |  |
| M2ナット | 12個（4×12で使うなら10個） | |  |  |
| Micro USBケーブル | 1本 | 通信ができるもの | ダイソー | 110円 |

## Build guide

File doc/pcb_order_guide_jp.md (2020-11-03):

# PCBなどの入手方法

## 基板・ボトムプレート

### ELECROWへ発注する場合

[ELECROW基板製造サービス](https://www.elecrow.com/pcb-manufacturing.html)から注文します。

アップロードするガーバーファイルは以下のものを使ってください。

| 概要 | URL | 寸法 |
| ---- | --- | --- |
| 基板 | https://github.com/e3w2q/ukiha-keyboard/blob/master/pcb/ukiha-gerber.zip?raw=true | 200×88mm |
| ボトムプレート | https://github.com/e3w2q/ukiha-keyboard/blob/master/pcb/ukiha-bottom-gerber.zip?raw=true | 200×88mm |

レジスト色はお好みの色を選択してください。

## ミドルアクリルプレート

### ELECROWへ発注する場合

[ELECROWアクリルカットサービス](https://www.elecrow.com/acrylic-cutting.html)から注文します。

アップロードするガーバーファイルは以下のいずれかを使ってください。

| 概要 | URL | 寸法 |
| ---- | --- | --- |
| 60キー用・中央で分割あり | https://github.com/e3w2q/ukiha-keyboard/blob/master/pcb/ukiha-middle-5x12.zip?raw=true | 100×112mm |
| 48キー用・中央で分割あり | https://github.com/e3w2q/ukiha-keyboard/blob/master/pcb/ukiha-middle-4x12.zip?raw=true | 100×112mm |
| 60キー用＋48キー用・中央で分割なし | https://github.com/e3w2q/ukiha-keyboard/blob/master/pcb/ukiha-middle-all.zip?raw=true | 205×99.5mm |

厚みは2.5mmまたはそれ以上としてください。

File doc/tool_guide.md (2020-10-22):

[English](tool_guide.md) / [日本語](tool_guide_jp.md)

# Tools and consumables

## Examples of procured products

This is a list of items that should be procured. The commentary is summarized below.

| Tools, consumables | Product examples | Examples of suppliers | Reference prices |
| ---- | ---- |  ---- |  ---- |
| Soldering iron | White light dial type temperature control soldering iron FX600 | https://www.amazon.co.jp/dp/B006MQD7M4 | 3,900 yen |
| Replacement iron tip | White light tip 2C type T18-C2 | https://www.amazon.co.jp/dp/B004OR7UBM | 478 yen |
| Soldering iron stand | HAKOKO iron stand 633-01 | https://www.amazon.co.jp/dp/B000TGNWCS | 1,680 yen |
| Solder blotter | Sanhayato Solder Shutaro NEO 45W type HSK-300 | https://www.amazon.co.jp/dp/B01FEV2BPG | 4,918 yen |
| Nippers | Engineer Micro Nipper NS-04 | https://www.amazon.co.jp/dp/B000TGJSWG | 1,414 yen |
| Precision screwdriver +0 | Engineer + Precision screwdriver set 6 DM-20 | https://www.amazon.co.jp/dp/B06XXXVPRY | 807 yen |
| Tester | OHM (Ohm Electric) Digital Multi Tester TDB-401 (04-1891) | https://www.amazon.co.jp/dp/B001TVKWWU | 2,543 yen |
| Solder | goot precision printed circuit board solder SD-62 | https://www.amazon.co.jp/dp/B0029LGAMA | 255 yen |
| Equiposhi adhesive two-component mixed type | Cemedine 5 minutes curing epoxy adhesive High Super 5 P15g set CA-188 | https://www.amazon.co.jp/dp/B0036WHO0S | 566 yen |
| Masking tape | Masking tape for 3M Scotch painting 18mm × 18m M40J-18 | https://www.amazon.co.jp/dp/B005JWNJZM | 95 yen |
| Sandpaper | KAKURI Paper File MIX Set, 12 Sheets | https://www.amazon.co.jp/dp/B01ARIEU0A | 436 yen |
| Total | | | 17,092 yen |

## Explanation

### Soldering iron

I do not recommend soldering irons from 100 yen shops.

From [WEBはんだ付け講座 はじめに・・](https://noseseiki.com/kisokouza/01.html)

> Currently, in Japan, soldering irons with no temperature control function are used by the majority of people who solder. These soldering irons have a too high tip temperature of 450-550 ° C. For this reason, most products soldered with this soldering iron will be overheated.

If you don't have much soldering experience or have done it a long time ago, we strongly recommend that you prepare one with temperature control.

### Replacement tip

Since the conical shape attached to the soldering iron from the beginning hits the target and the point, it is difficult for heat to be transmitted, and solder may be placed due to insufficient heating, so replace it with the 2C tip and heat on the surface It is easy to do it if you can.

### Soldering iron stand

Necessary for safely placing the soldering iron.

### Solder blotter or wire

It is good to have it because it is not necessary when soldering fails.

### Nipper

It is used for cutting board / biscuits, cutting diode legs / pin headers.

Nippers are not recommended for 100 yen shops for the following reasons.

- Sharpness is not so good, and it is difficult to cut the diode feet and pin header.
- Since the blade is not a sword, it cannot be cut

### Tester

Necessary for problem isolation when keys cannot be entered.

All you need is a conduction mode.

### Electronic work solder

Leaded type is easy to work with.

Since there are no particularly small parts used for SU120, even a 1mm one can work well, but 0.8mm seems to melt the solder easily.

### Epoxy adhesive two-component mixed type

Used for Pro Micro baldness prevention processing.

### Masking tape

It is used to fix parts when turning the board over by soldering.

## Web page for reference (Japanese)

- [Helix キーボードキットの製作に必要な工具メモ - GitHub](https://gist.github.com/mtei/6957107a676ddfa85bde0ae41f8fa849)
- [自作キーボードを作るために必要なもの - 自作キーボード温泉街の歩き方](https://salicylic-acid3.hatenablog.com/entry/2018/11/24/自作キーボードを作るために必要なもの)
- [自作キーボードの組み立てに使っている工具 | yfuku docs](https://yfuku.com/blog/keyboard/keybord_build_tool/)
- [elephant42 の組み立てかた#工具の準備 · illness072/elephant42](https://github.com/illness072/elephant42/blob/master/docs/build-guide.md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)
- [基礎からわかる！自キ入門講座 第8回「自作キーボードのつくりかた #2」 - YouTube](https://salicylic-acid3.hatenablog.com/entry/2018/11/24/自作キーボードを作るために必要なもの)

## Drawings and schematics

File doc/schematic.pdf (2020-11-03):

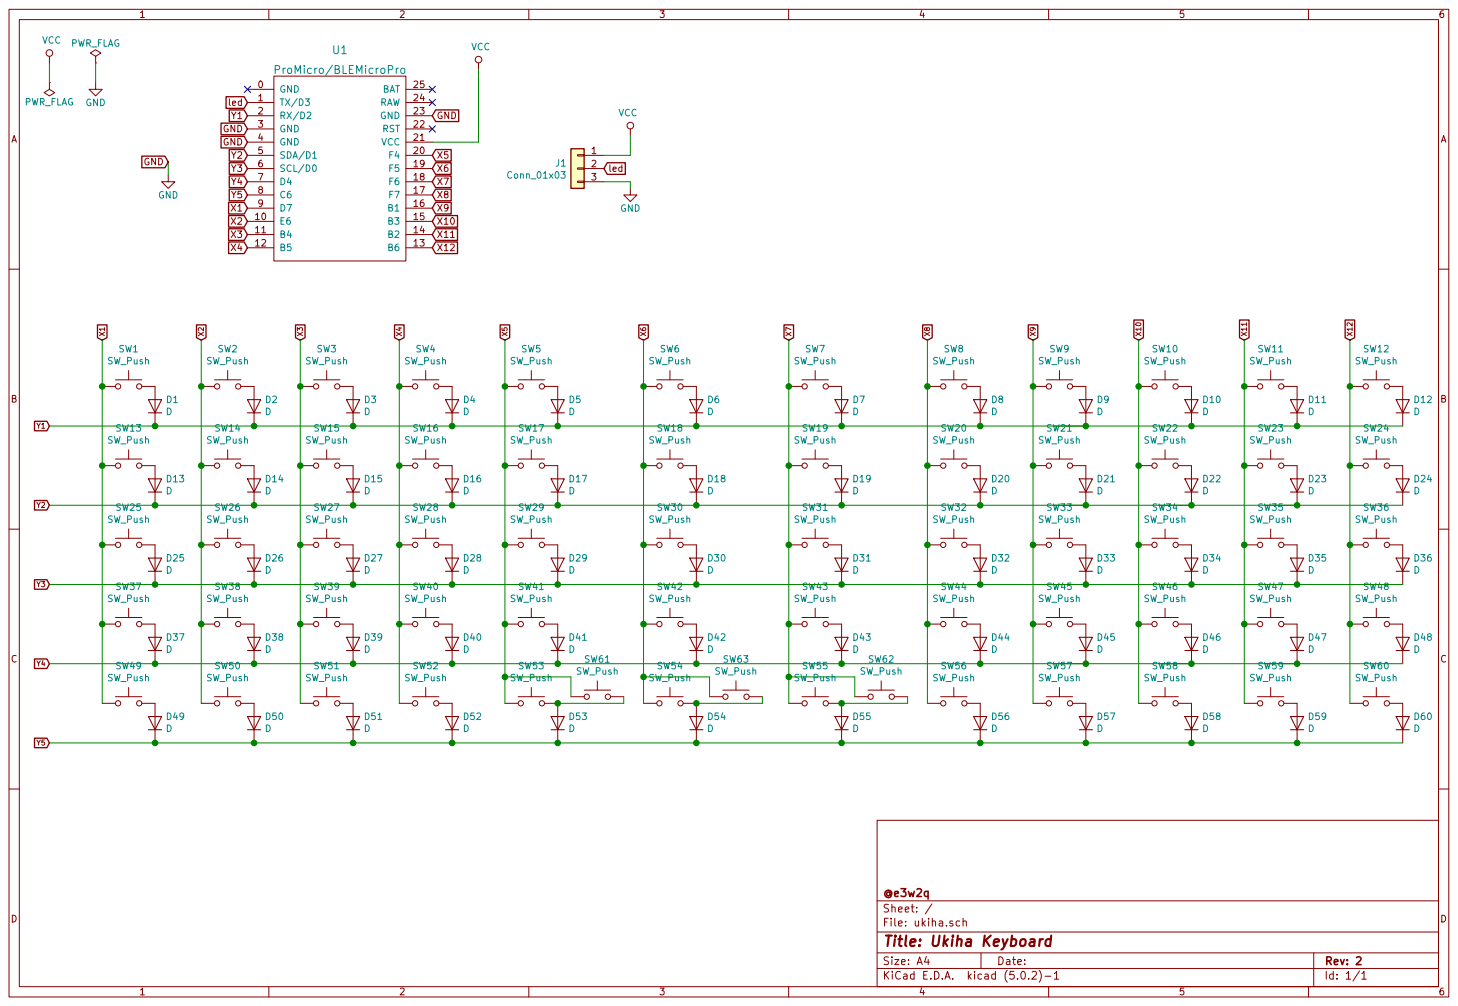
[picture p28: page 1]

File: ukiha.sch Sheet: / @e3w2q

Id: 1/1 Title: Ukiha Keyboard

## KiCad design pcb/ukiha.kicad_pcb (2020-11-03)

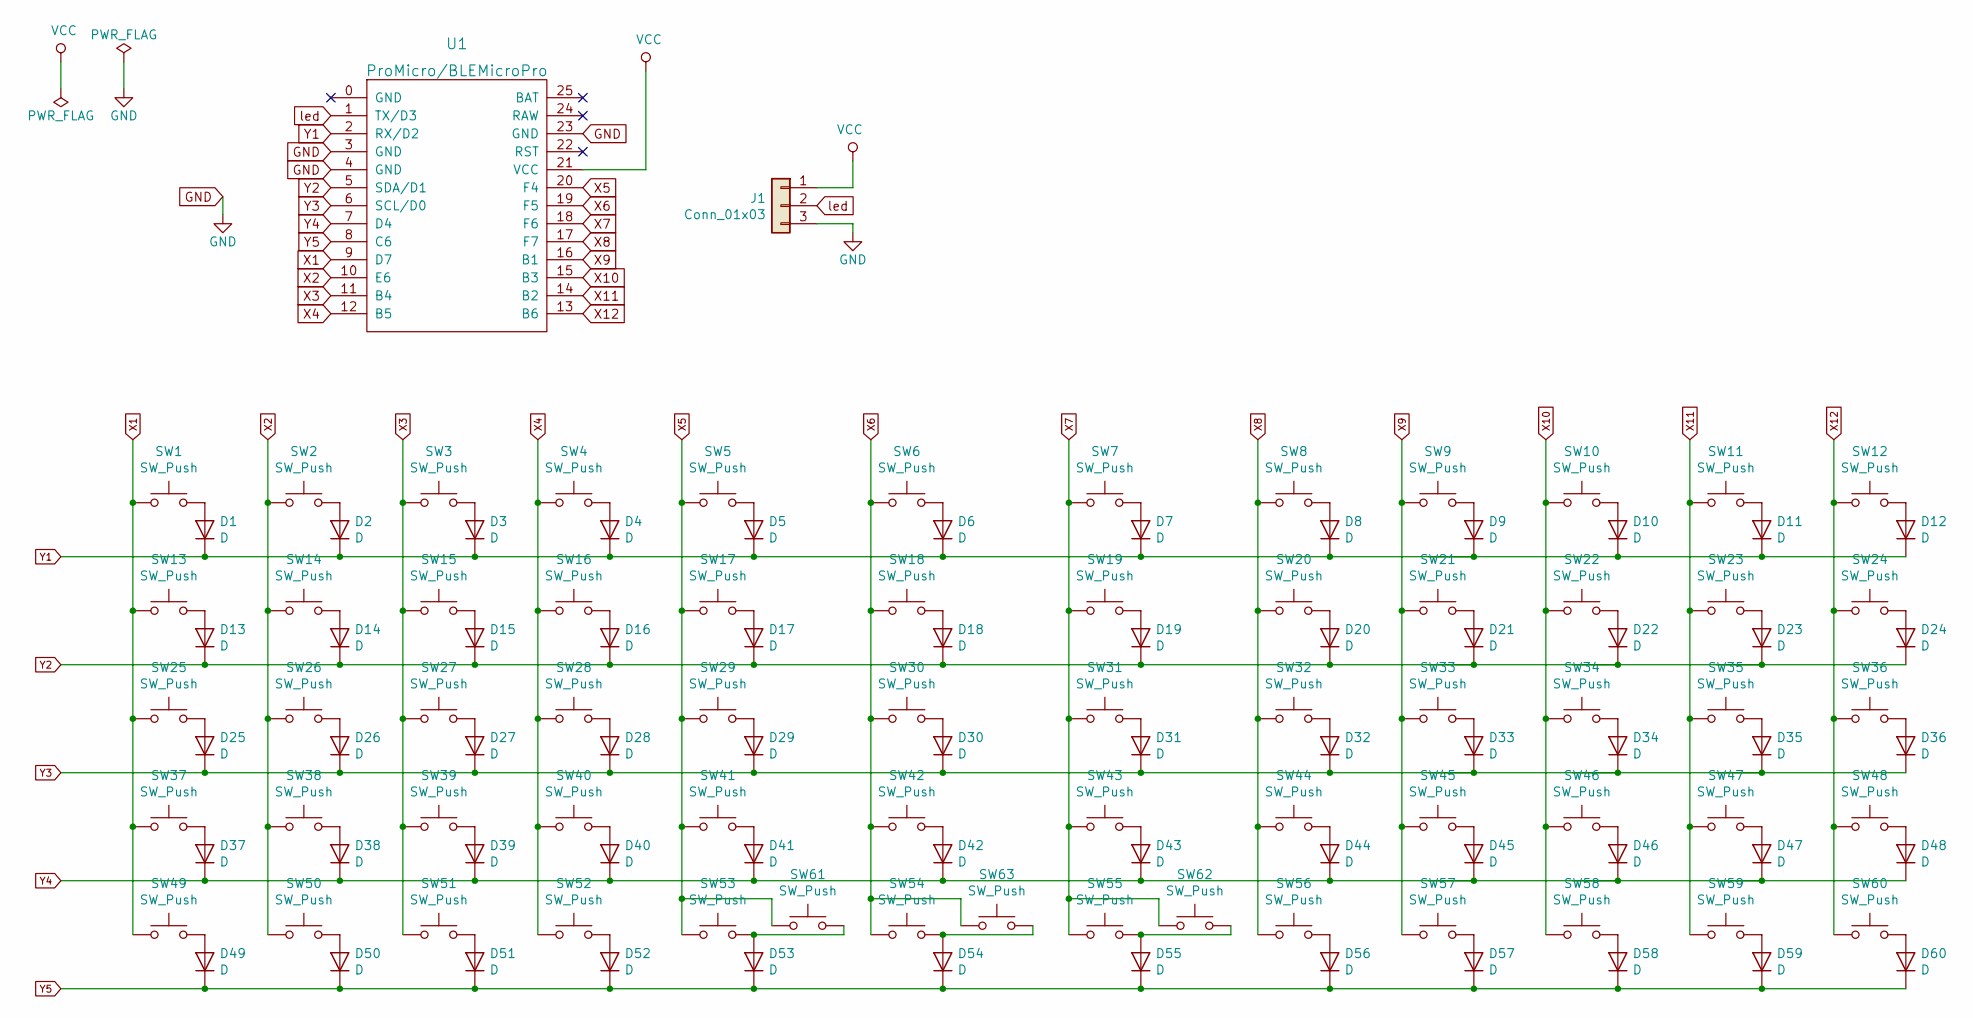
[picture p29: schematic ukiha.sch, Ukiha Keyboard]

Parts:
D1, D2, D3, D4, D5, D6, D7, D8, D9, D10, D11, D12, D13, D14, D15, D16, D17, D18, D19, D20, D21, D22, D23, D24, D25, D26, D27, D28, D29, D30, D31, D32, D33, D34, D35, D36, D37, D38, D39, D40, D41, D42, D43, D44, D45, D46, D47, D48, D49, D50, D51, D52, D53, D54, D55, D56, D57, D58, D59, D60: D; diode_SMD
J1: Conn_01x03; StripLED_rev2
SW1, SW2, SW3, SW4, SW5, SW6, SW7, SW8, SW9, SW10, SW11, SW12, SW13, SW14, SW15, SW16, SW17, SW18, SW19, SW20, SW21, SW22, SW23, SW24, SW25, SW26, SW27, SW28, SW29, SW30, SW31, SW32, SW33, SW34, SW35, SW36, SW37, SW38, SW39, SW40, SW41, SW42, SW43, SW44, SW45, SW46, SW47, SW48, SW49, SW50, SW51, SW52, SW53, SW54, SW55, SW56, SW57, SW58, SW59, SW60, SW61, SW62, SW63: SW_Push; CherryMX_MidHeight_16mm_rev2
U1: ProMicro/BLEMicroPro; ArduinoProMicro_ConThrough

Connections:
GND: J1.3, U1.3 (GND), U1.4 (GND), U1.23 (GND)
unnamed: D1.2 (A), SW1.2
unnamed: D2.2 (A), SW2.2
unnamed: D3.2 (A), SW3.2
unnamed: D4.2 (A), SW4.2
unnamed: D5.2 (A), SW5.2
unnamed: D6.2 (A), SW6.2
unnamed: D7.2 (A), SW7.2
unnamed: D8.2 (A), SW8.2
unnamed: D9.2 (A), SW9.2
unnamed: D10.2 (A), SW10.2
unnamed: D11.2 (A), SW11.2
unnamed: D12.2 (A), SW12.2
unnamed: D13.2 (A), SW13.2
unnamed: D14.2 (A), SW14.2
unnamed: D15.2 (A), SW15.2
unnamed: D16.2 (A), SW16.2
unnamed: D17.2 (A), SW17.2
unnamed: D18.2 (A), SW18.2
unnamed: D19.2 (A), SW19.2
unnamed: D20.2 (A), SW20.2
unnamed: D21.2 (A), SW21.2
unnamed: D22.2 (A), SW22.2
unnamed: D23.2 (A), SW23.2
unnamed: D24.2 (A), SW24.2
unnamed: D25.2 (A), SW25.2
unnamed: D26.2 (A), SW26.2
unnamed: D27.2 (A), SW27.2
unnamed: D28.2 (A), SW28.2
unnamed: D29.2 (A), SW29.2
unnamed: D30.2 (A), SW30.2
unnamed: D31.2 (A), SW31.2
unnamed: D32.2 (A), SW32.2
unnamed: D33.2 (A), SW33.2
unnamed: D34.2 (A), SW34.2
unnamed: D35.2 (A), SW35.2
unnamed: D36.2 (A), SW36.2
unnamed: D37.2 (A), SW37.2
unnamed: D38.2 (A), SW38.2
unnamed: D39.2 (A), SW39.2
unnamed: D40.2 (A), SW40.2
unnamed: D41.2 (A), SW41.2
unnamed: D42.2 (A), SW42.2
unnamed: D43.2 (A), SW43.2
unnamed: D44.2 (A), SW44.2
unnamed: D45.2 (A), SW45.2
unnamed: D46.2 (A), SW46.2
unnamed: D47.2 (A), SW47.2
unnamed: D48.2 (A), SW48.2
unnamed: D49.2 (A), SW49.2
unnamed: D50.2 (A), SW50.2
unnamed: D51.2 (A), SW51.2
unnamed: D52.2 (A), SW52.2
unnamed: D53.2 (A), SW53.2, SW61.2
unnamed: D54.2 (A), SW54.2, SW63.2
unnamed: D55.2 (A), SW55.2, SW62.2
unnamed: D56.2 (A), SW56.2
unnamed: D57.2 (A), SW57.2
unnamed: D58.2 (A), SW58.2
unnamed: D59.2 (A), SW59.2
unnamed: D60.2 (A), SW60.2
VCC: J1.1, U1.21 (VCC)
X1: SW1.1, SW13.1, SW25.1, SW37.1, SW49.1, U1.9 (D7)
X2: SW2.1, SW14.1, SW26.1, SW38.1, SW50.1, U1.10 (E6)
X3: SW3.1, SW15.1, SW27.1, SW39.1, SW51.1, U1.11 (B4)
X4: SW4.1, SW16.1, SW28.1, SW40.1, SW52.1, U1.12 (B5)
X5: SW5.1, SW17.1, SW29.1, SW41.1, SW53.1, SW61.1, U1.20 (F4)
X6: SW6.1, SW18.1, SW30.1, SW42.1, SW54.1, SW63.1, U1.19 (F5)
X7: SW7.1, SW19.1, SW31.1, SW43.1, SW55.1, SW62.1, U1.18 (F6)
X8: SW8.1, SW20.1, SW32.1, SW44.1, SW56.1, U1.17 (F7)
X9: SW9.1, SW21.1, SW33.1, SW45.1, SW57.1, U1.16 (B1)
X10: SW10.1, SW22.1, SW34.1, SW46.1, SW58.1, U1.15 (B3)
X11: SW11.1, SW23.1, SW35.1, SW47.1, SW59.1, U1.14 (B2)
X12: SW12.1, SW24.1, SW36.1, SW48.1, SW60.1, U1.13 (B6)
Y1: D1.1 (K), D2.1 (K), D3.1 (K), D4.1 (K), D5.1 (K), D6.1 (K), D7.1 (K), D8.1 (K), D9.1 (K), D10.1 (K), D11.1 (K), D12.1 (K), U1.2 (RX/D2)
Y2: D13.1 (K), D14.1 (K), D15.1 (K), D16.1 (K), D17.1 (K), D18.1 (K), D19.1 (K), D20.1 (K), D21.1 (K), D22.1 (K), D23.1 (K), D24.1 (K), U1.5 (SDA/D1)
Y3: D25.1 (K), D26.1 (K), D27.1 (K), D28.1 (K), D29.1 (K), D30.1 (K), D31.1 (K), D32.1 (K), D33.1 (K), D34.1 (K), D35.1 (K), D36.1 (K), U1.6 (SCL/D0)
Y4: D37.1 (K), D38.1 (K), D39.1 (K), D40.1 (K), D41.1 (K), D42.1 (K), D43.1 (K), D44.1 (K), D45.1 (K), D46.1 (K), D47.1 (K), D48.1 (K), U1.7 (D4)
Y5: D49.1 (K), D50.1 (K), D51.1 (K), D52.1 (K), D53.1 (K), D54.1 (K), D55.1 (K), D56.1 (K), D57.1 (K), D58.1 (K), D59.1 (K), D60.1 (K), U1.8 (C6)
led: J1.2, U1.1 (TX/D3)

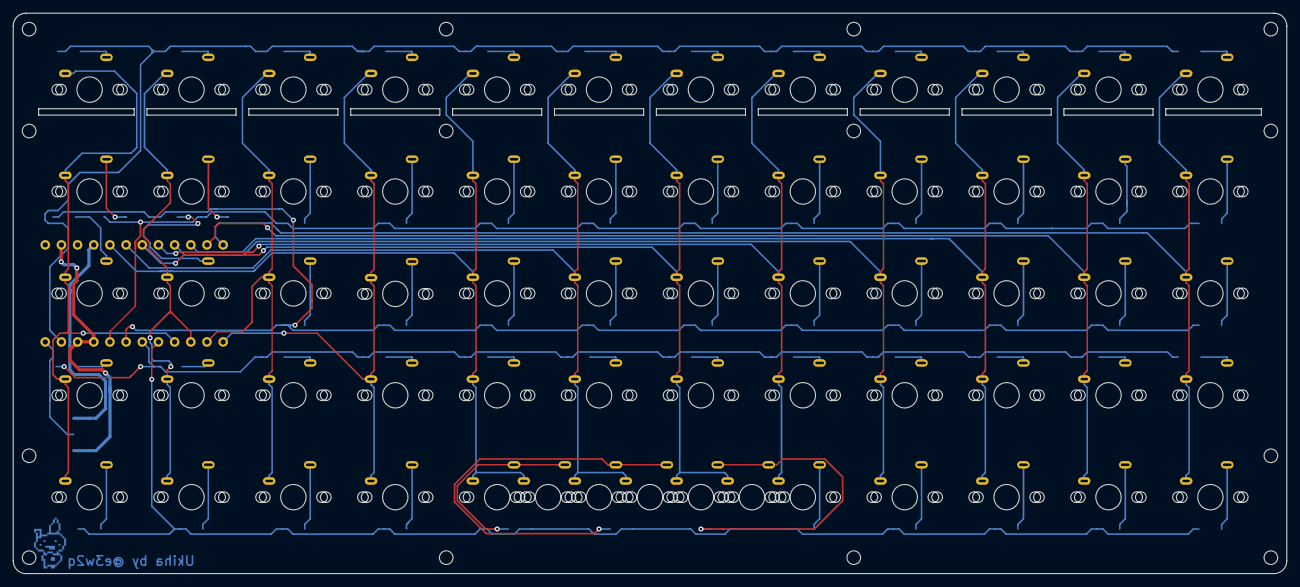
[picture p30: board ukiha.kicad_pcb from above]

Board: 2 copper layers, 200.0 x 88.0 mm, 125 parts (1 on the bottom side), 80 nets.

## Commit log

2020-10-22 1st commit
    [ukiha-bottom.kicad_pcb, ukiha-draft.kicad_pcb, ukiha-middle.kicad_pcb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]
2020-10-24 Add 48 key middle plate
    [ukiha-draft.kicad_pcb, ukiha-middle-4x12.kicad_pcb, ukiha-middle-5x12.kicad_pcb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]
2020-11-03 Fix PCB
    [ukiha-bottom.kicad_pcb, ukiha-middle-all.kicad_pcb, ukiha.kicad_pcb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]
2021-03-10 Fix screw hole position
    [ukiha-middle-4x12.kicad_pcb, ukiha-middle-5x12.kicad_pcb]

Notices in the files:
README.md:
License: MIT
